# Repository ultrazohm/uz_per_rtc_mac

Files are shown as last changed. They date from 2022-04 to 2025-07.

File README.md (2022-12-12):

# APU Feature Extension Card for the UltraZohm's CarrierBoard/BaseSystem #

This PCB will add some crucial hardware peripherals to the existing systems by means of an extension board to be mounted within the chassis (but not using any of the A/D slots).

### Feature List/Requests/Issues ###

* Low-level configuration storage: Cf. [Issue #124 in the UltraZohm CarrierBoard repo](https://bitbucket.org/ultrazohm/ultrazohm_carrierboard/issues/124/low-level-configuration-storage-ethernet)
* Probably additional user interfaces (buttons/LEDs)
* High-speed storage for OS, application and logs: Cf. [Issue #2 in this repository](https://bitbucket.org/ultrazohm/uz_per_rtc_mac/issues/2/ssd-integration-options)

### How do I get set up? / Contribution guidelines / Who do I talk to? ###

* Eyke and Martin
* Feel free to open an issue here

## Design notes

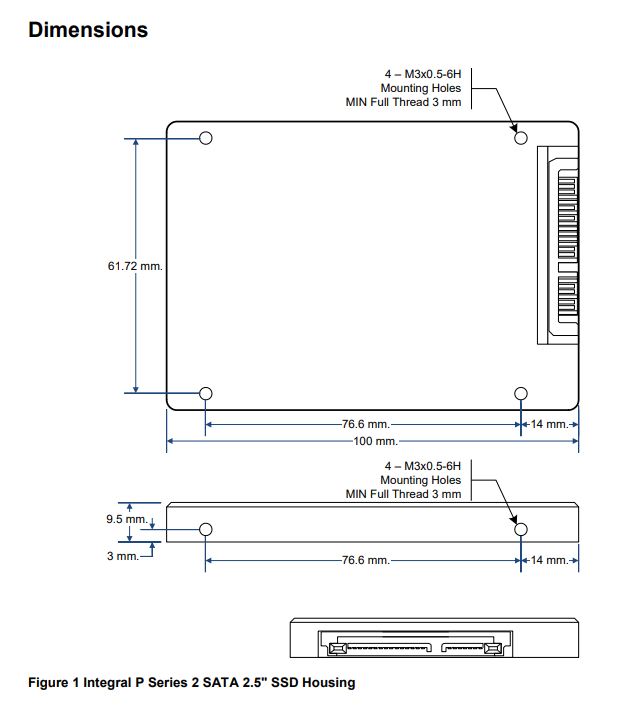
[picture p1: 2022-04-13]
ssd_dimensions.png

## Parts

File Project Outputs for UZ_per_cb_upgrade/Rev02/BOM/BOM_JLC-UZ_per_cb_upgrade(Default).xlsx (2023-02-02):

Quantity | Comment | Designator | MF | MPN | Value | Description | Footprint | Package | Voltage | Dielectric | LCSC Part # | JLCSMT Rotation
1 | HMB1206-03 | B1 |  |  | HMB1206-03 | AUDIO PIEZO BUZZER THT | THT12X6 |  |  |  | C96101
1 | HMB1206-05 | B2 |  |  | HMB1206-05 | AUDIO PIEZO BUZZER THT | THT12X6 |  |  |  | C96095
1 | S8421-45R | BT1 |  |  |  | BATTERY HOLDER COIN 20MM SMD | FP-S8421-45R-MFG |  |  |  | C964790
17 | 100nF | C1, C2, C7, C8, C9, C10A, C10B, C11, C13, C14, C18, C26, C29, C32, C35, C37, C38 |  |  | 100nF | CAP 0603 (1608 Metric) SMD | C_0603(1608)100_L | 0603 |  |  | C14663
12 | 10µF | C3, C4, C12, C20, C21, C22, C23, C24, C27, C30, C33, C36 | Taiyo Yuden | GMK316BJ106KL-T | 10µF | Capacitor 1206 | C_1206 | 1206 | 35 V | X5R | C13585
2 | 10pF | C5, C6 |  |  | 10pF | CAP 0603 (1608 Metric) SMD | C_0603(1608)100_L | 0603 |  |  | C1634
2 | 16pF | C15, C16 |  |  | 16pF | CAP 0603 (1608 Metric) SMD | C_0603(1608)100_L | 0603 |  |  | C1646
2 | 220uF | C17, C19 |  |  | 220uF | ALUMINUM ELECTROLYTIC CAPACITOR | CAPAE9083X105M | 8x10 | 35V |  | C311611
4 | 10nF | C25, C28, C31, C34 |  |  | 10nF | CAP 0603 (1608 Metric) SMD | C_0603(1608)100_L | 0603 |  |  | C100042
1 | 150060RS75000 | D1 | Wuerth Elektronik | 150060RS75000 | 150060RS75000 | WL-SMCW SMD Mono-color Chip LED Waterclear, size 0603, Red, 2 V, 140° | WL-SMCW_0603 | 0603 |  |  | C2286
1 | BAT54C | D2 |  |  |  | Schottky Barrier Diode, 30 V, 2 uA, -55 to 150 degC, 3-Pin SOT23, RoHS, Tape and Reel | NXP-SOT23-3_V |  |  |  | C37704
1 | 1N4148W-7-F | D4 |  |  |  | Fast Switching Diode, 100 V, 0.15 A, -65 to 150 degC, 2-Pin?SOD123, RoHS, Tape and Reel | DIOD-SOD123-2_V |  |  |  | C81598
8 | 150060GS75000 | D5, D6, D7, D8, D9, D10, D11, D12 | Wuerth Elektronik | 150060GS75000 | 150060GS75000 | WL-SMCW SMD Mono-color Chip LED Waterclear, size 0603, Green, 3.2 V, 140° | WL-SMCW_0603 | 0603 |  |  | C72043
2 | HYCW02-SATA07-250B | J1, J2 |  |  |  | CONN HEADER 7POS HOR | HYCW02-SATA07-250B |  |  |  | C2926811
2 | M.2 NGFF Key B Platform Side | J3, J4 |  |  |  | M.2 NGFF Connector Key B Platform Side | 2199230-3 |  |  |  | C590854
2 | M.2 NGFF Socket 2242BM | J3a, J4a |  |  |  | M.2 NGFF Socket 2242BM Snap | M.2-NGFF-Socket-2242BM |  |  |  | C5301784
1 | M.2 NGFF Socket 2280BM | J3b |  |  |  | M.2 NGFF Socket 2280BM Snap | M.2-NGFF-Socket-2280BM |  |  |  | C5301784
2 | 2k | R1, R2 | Yageo | RC0603FR-072KL | 2k | SMD Resistor 0603 | R_0603_N | 0603 | 75 V |  | C22975
9 | 680R | R3, R18, R22, R23, R28, R31, R32, R33, R34 | Bourns | CR0603-FX-3901ELF | 680R | SMD Resistor 0603 | R_0603_N | 0603 | 75V |  | C23228
39 | 0R | R5, R6, R7, R10, R11, R12, R13, R14, R15, R25, R26, R27, R29, R30, R36, R38, R52B, R54A, R54B, R55A, R55B, R56A, R56B, R57A, R58A, R58B, R59, R60, R63, R64, R65, R66, R67, R68, R69, R70, R72, R73, R86 |  |  | 0R | SMD Resistor 0603 | R_0603_N | 0603 | 75V |  | C21189
10 | 10k | R35, R37, R39, R40, R41, R47, R49, R62, R76, R77 | Yageo | RC0603FR-072KL | 10k | SMD Resistor 0603 | R_0603_N | 0603 | 75 V |  | C25804
1 | 100k | R42 |  |  | 100k | SMD Resistor 0603 | R_0603_N | 0603 |  |  | C25803
4 | 33 | R78, R80, R82, R84 |  |  | 33 | SMD Resistor 0603 | R_0603_N | 0603 |  |  | C108661
4 | 49.9 | R79, R81, R83, R85 |  |  | 49.9 | SMD Resistor 0603 | R_0603_N | 0603 |  |  | C114625
1 | 475 | R87 |  |  | 475 | SMD Resistor 0603 | R_0603_N | 0603 |  |  | C137716
3 | EVQ-Q2F03W | SW1, SW2, SW3 |  |  |  | SWITCH TACTILE SPST-NO 0.02A 15V | FP-EVQ-Q2F03W-MFG |  |  |  | C318884
1 | PCF8563T/5,518 | U1 |  |  |  | IC RTC CLK/CALENDAR I2C 8-SOIC | FP-SOT96-1-IPC_B | SOT96-1 |  |  | C7440
1 | AT24C02C-SSHM-T | U2 |  |  |  | IC EEPROM 2K I2C 1MHZ 8SOIC | FP-C04-057-SN-MFG | C04-057-SN |  |  | C6203
1 | PCA9535PWR | U3 |  |  |  | IC I/O EXPANDER I2C 16B 24TSSOP | FP-PW0024A-MFG |  |  |  | C255606
2 | 24AA025E48T-I/SN | U4A, U4B |  |  |  | 2K bits I2C™ Serial EEPROM with EUI-48™ Node Identity, 1.7 to 5.5 V, 400 kHz, -40 to 85 degC, 8-pin SOIC (SN8), Tape and Reel | MCHP-SOIC-SN8_L |  |  |  | C2060925
1 | AOZ1360AIL | U5 |  |  |  | 28V Programmable Current-Limited Load Switch | SOIC127P600X175-8N |  |  |  | C146821
1 | ULN2803ADWR | U6 |  |  |  | Darlington Transistor Array, -40 to 85 degC, 18-Pin SOIC (DW), Green (RoHS & no Sb/Br), Tape and Reel | DW0018A_L |  |  |  | C181731
1 | TDKxx-yySzz | U8 |  |  |  | Isolated Single Output DC/DC Converter, 15/20/30 W, 2x6-Pin DIP (*M*iddle and *S*ide pin-out in one footprint/package, hopefully) | TDKxx-yySzz |  |  |  | C570789
1 | AZ1084CD-3.3TRG1 | U9 |  |  |  | 5A Low Dropout Positive Regulators, 3-pin TO-252-2(DPAK) | DPAK457P1010X238-3N |  |  |  | C151391
1 | PI6C557-03ALEX | U10 |  |  |  | Clock Generators & Support Products PCI express Gen 2 2 ouput clock gen | SOP65P640X120-16N |  |  |  | C500785
1 | IPL1-106-01-L-D-K | X1 | SAMTEC | IPL1-106-01-L-D-K | IPL1-106-01-L-D-K | 2.54mm Double Row Terminal Assembly, Right-Angled | IPL1-106-01-L-D-K |  |  |  | C5295959
2 | IPL1-113-02-L-D-K | X5, X6 |  |  |  | IPL1-113-02-L-D-K | IPL1-113-02-L-D-K |  |  |  | C5290052
1 | ABS07-32.768KHz-T | Y1 |  |  |  | CRYSTAL 32.7680KHZ 12.5PF SMD | FP-ABS07-MFG |  |  |  | C32346
1 | Q22FA12800120 | Y2 |  |  |  | SMD Crystal Resonators 24MHz +/-10ppm SMD-2016_4P RoHS | Q22FA12800120

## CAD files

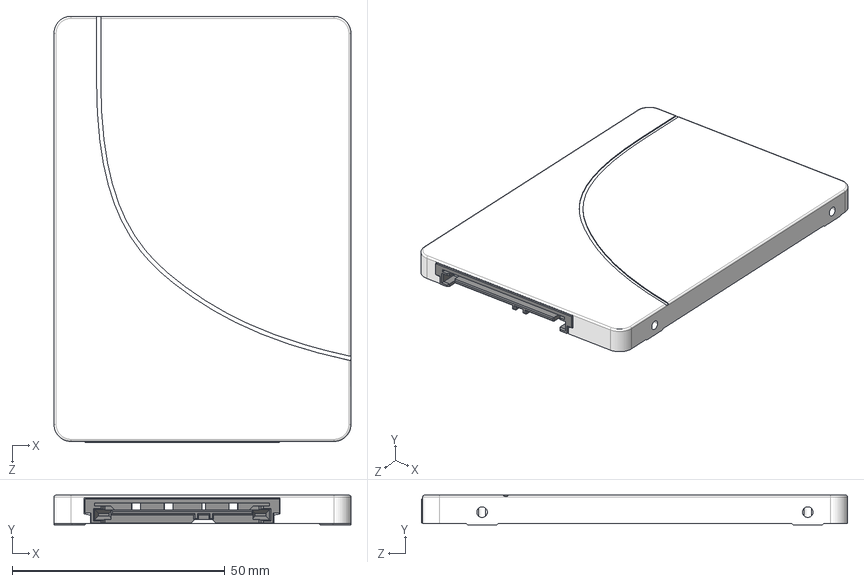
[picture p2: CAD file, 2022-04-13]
3D/Standard 520 model.STEP
69.8 x 7.00 x 100.3 mm

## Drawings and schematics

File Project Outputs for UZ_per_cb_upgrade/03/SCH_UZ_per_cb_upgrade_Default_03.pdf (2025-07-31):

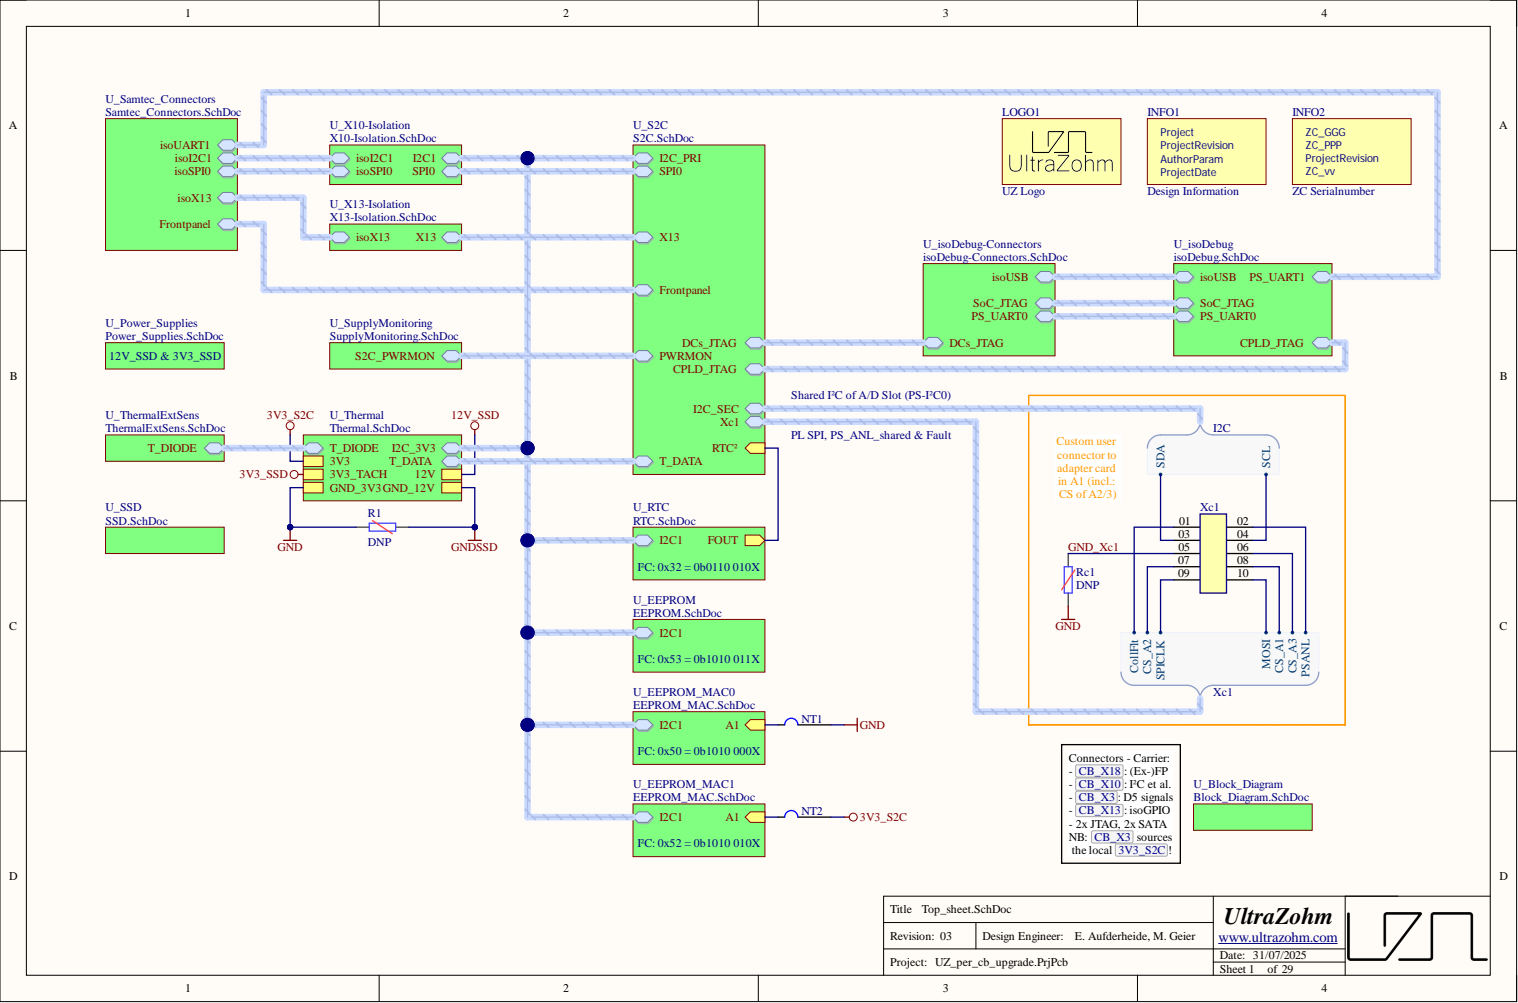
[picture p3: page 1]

Shared I²C of A/D Slot (PS-I²C0)

05 | | 06
07 | | 08
09 | | 10

Revision:

Date:

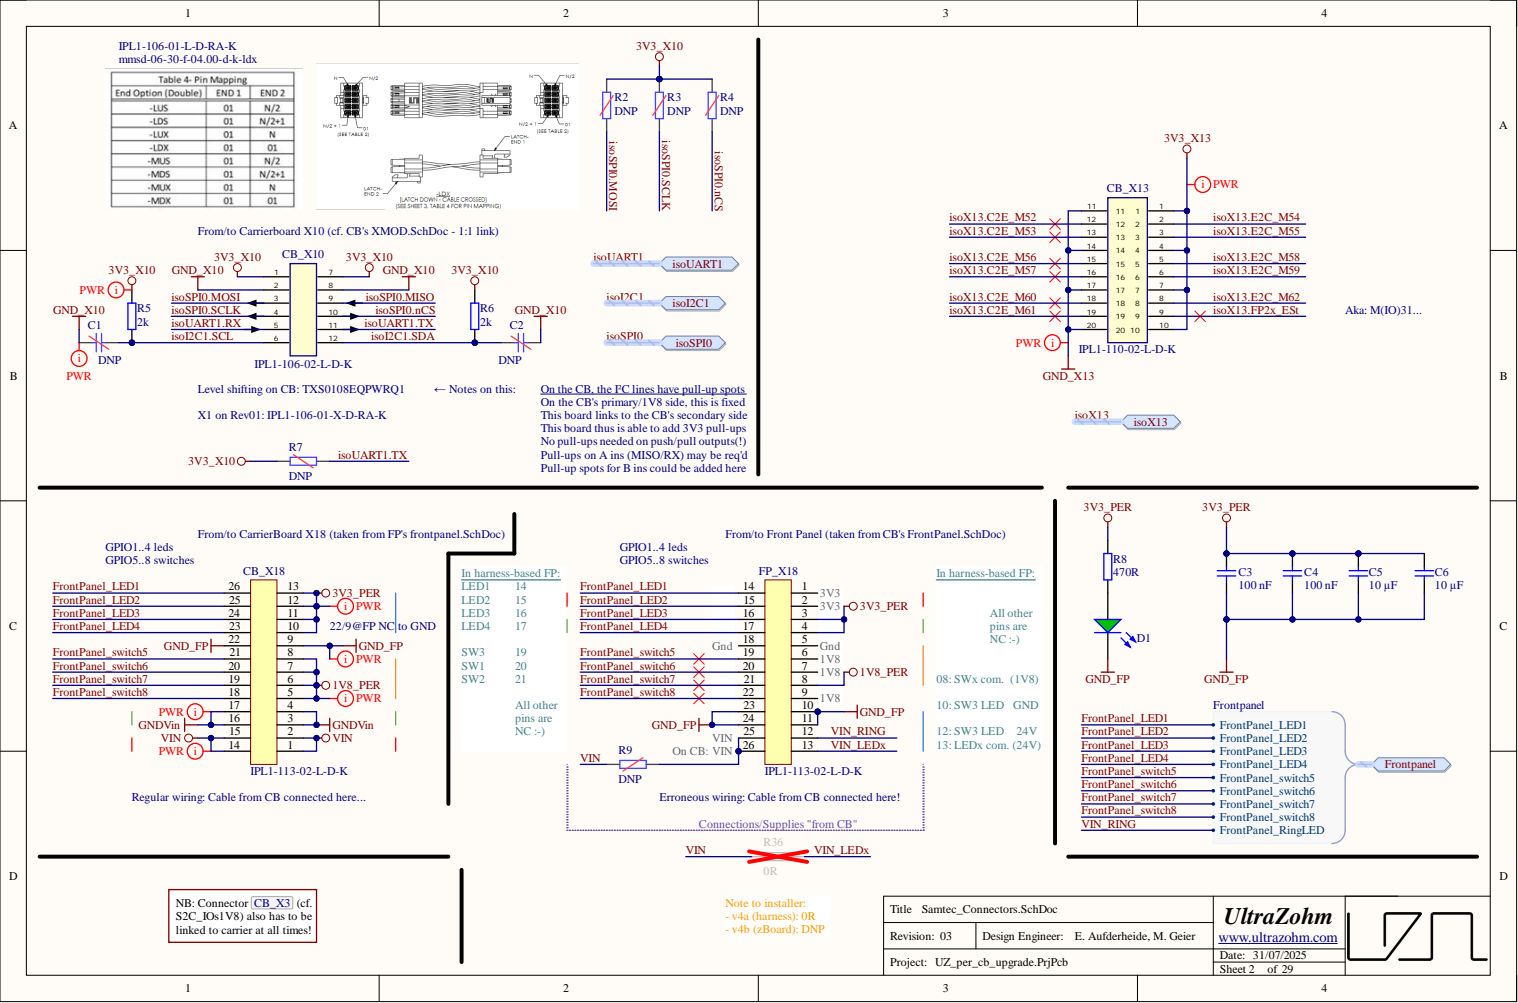
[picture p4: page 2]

From/to Carrierboard X10 (cf. CB's XMOD.SchDoc - 1:1 link)

Level shifting on CB: TXS0108EQPWRQ1

On the CB's primary/1V8 side, this is fixed
This board links to the CB's secondary side
This board thus is able to add 3V3 pull-ups
No pull-ups needed on push/pull outputs(!)
Pull-ups on A ins (MISO/RX) may be req'd
Pull-up spots for B ins could be added here

From/to CarrierBoard X18 (taken from FP's frontpanel.SchDoc)

From/to Front Panel (taken from CB's FrontPanel.SchDoc)

In harness-based FP:

NB: Connector CB_X3 (cf.
S2C_IOs1V8) also has to be
linked to carrier at all times!

Rev i s n : | Des gn E gi neer: E. A u fderhei de, M. Geier

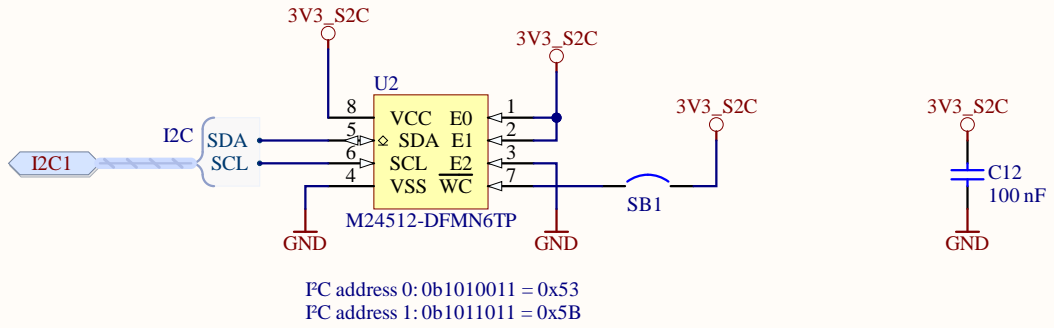
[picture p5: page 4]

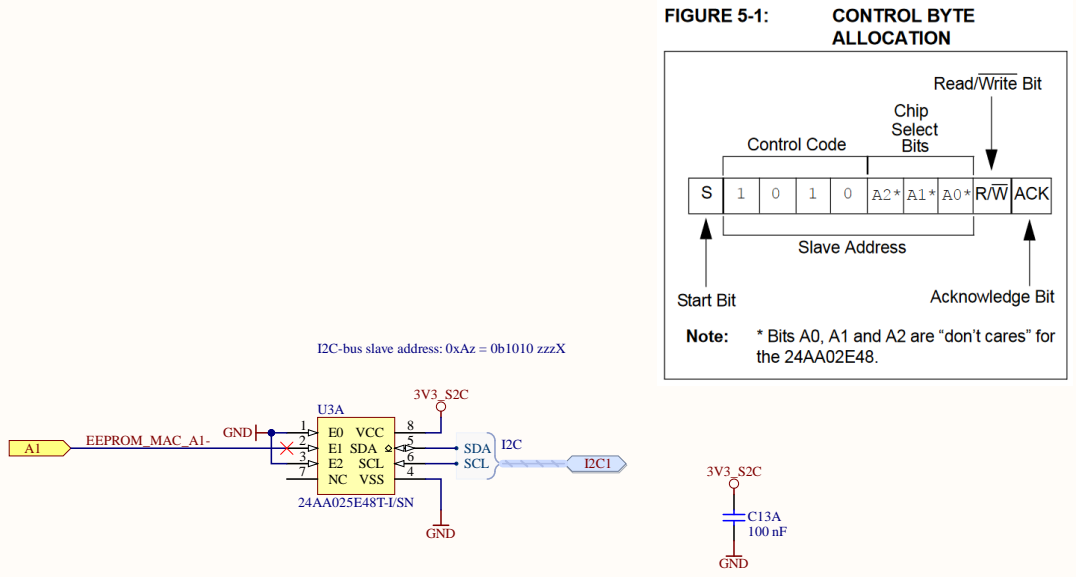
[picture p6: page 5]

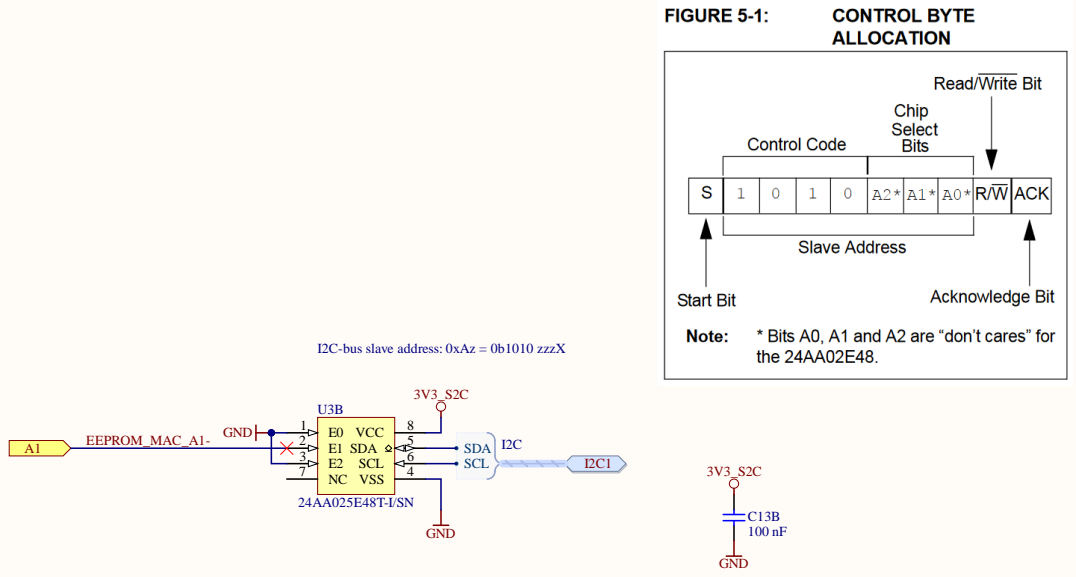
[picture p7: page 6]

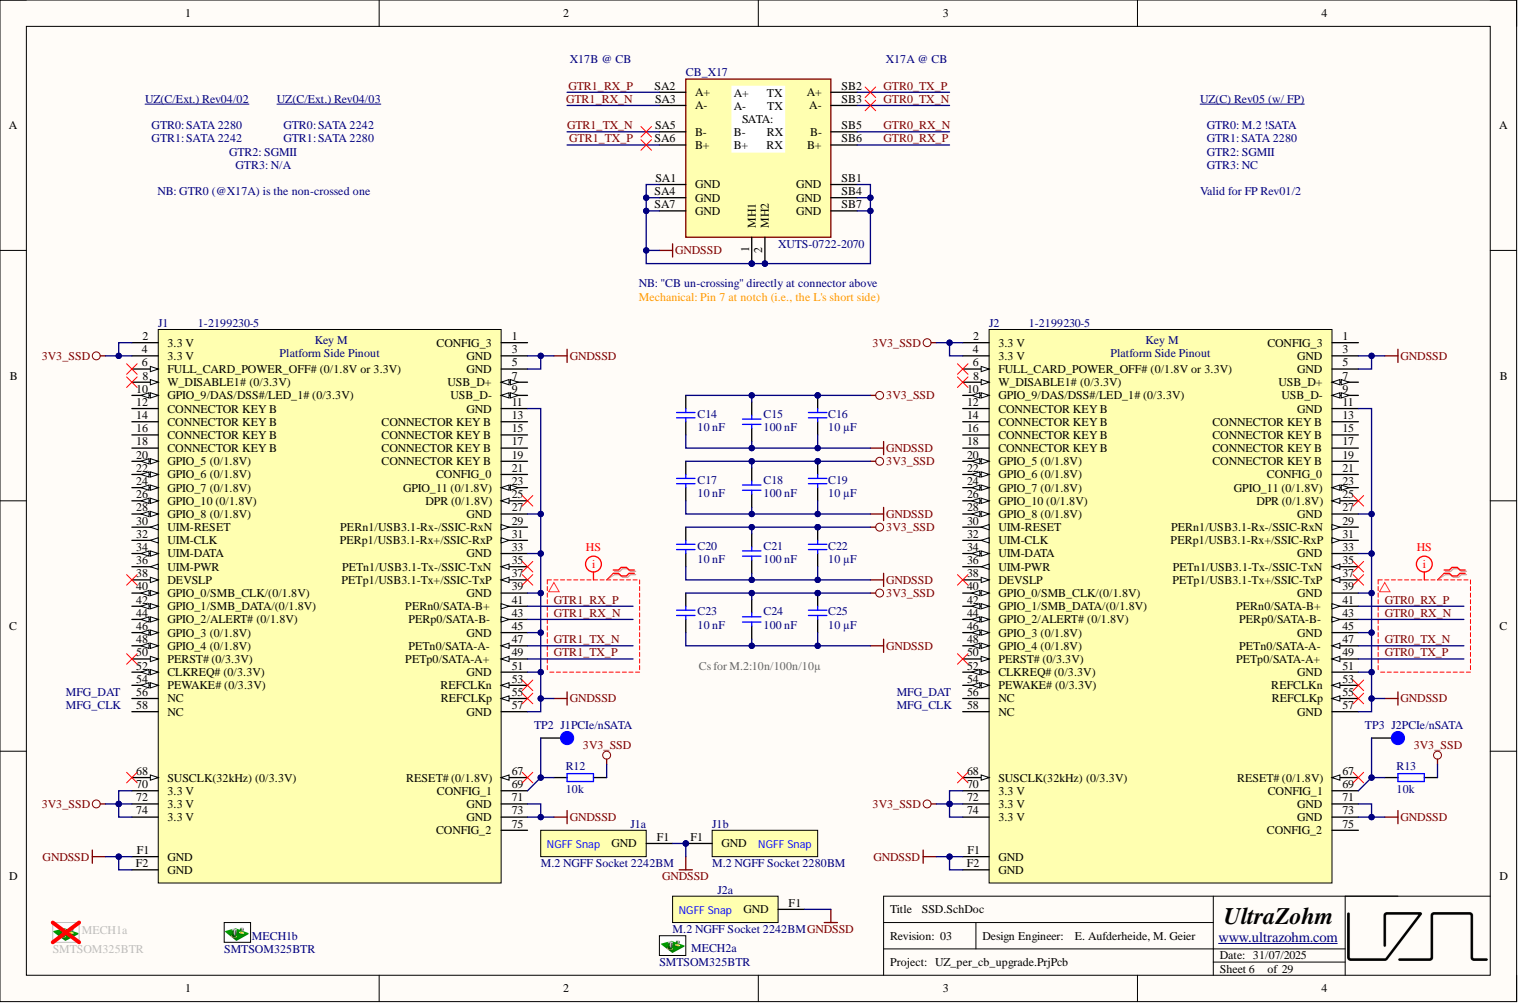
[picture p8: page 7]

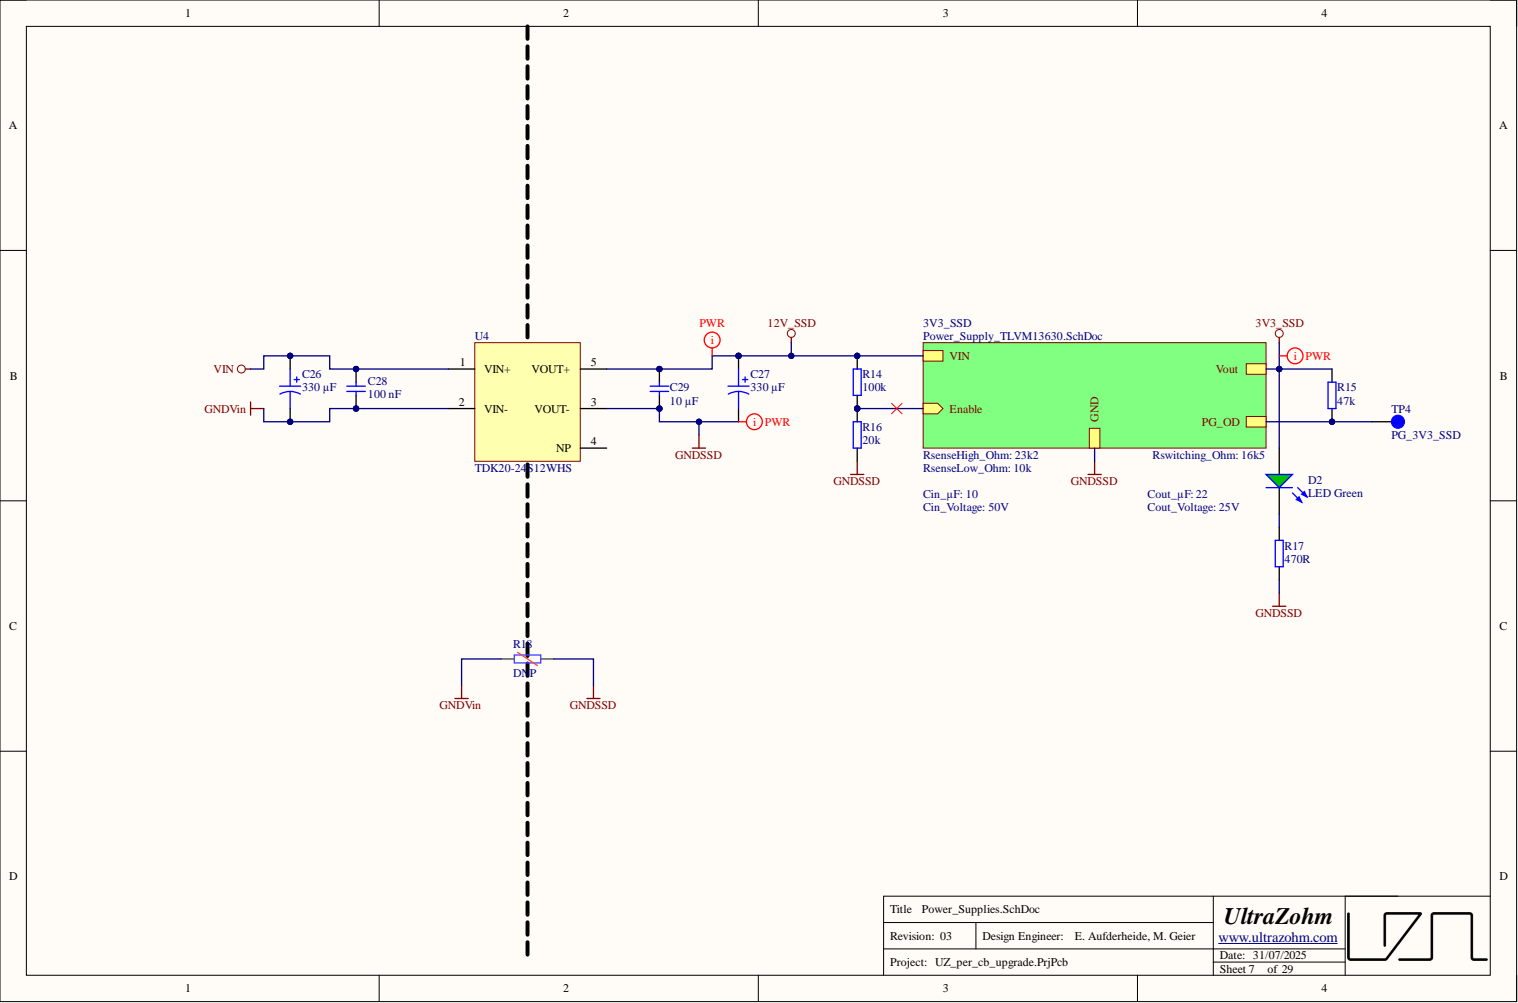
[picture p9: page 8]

E nab l e

2 8

1 8
1 9

1 7 | 9
2 9 | 1 0

VCCv 2 3 | 1 2

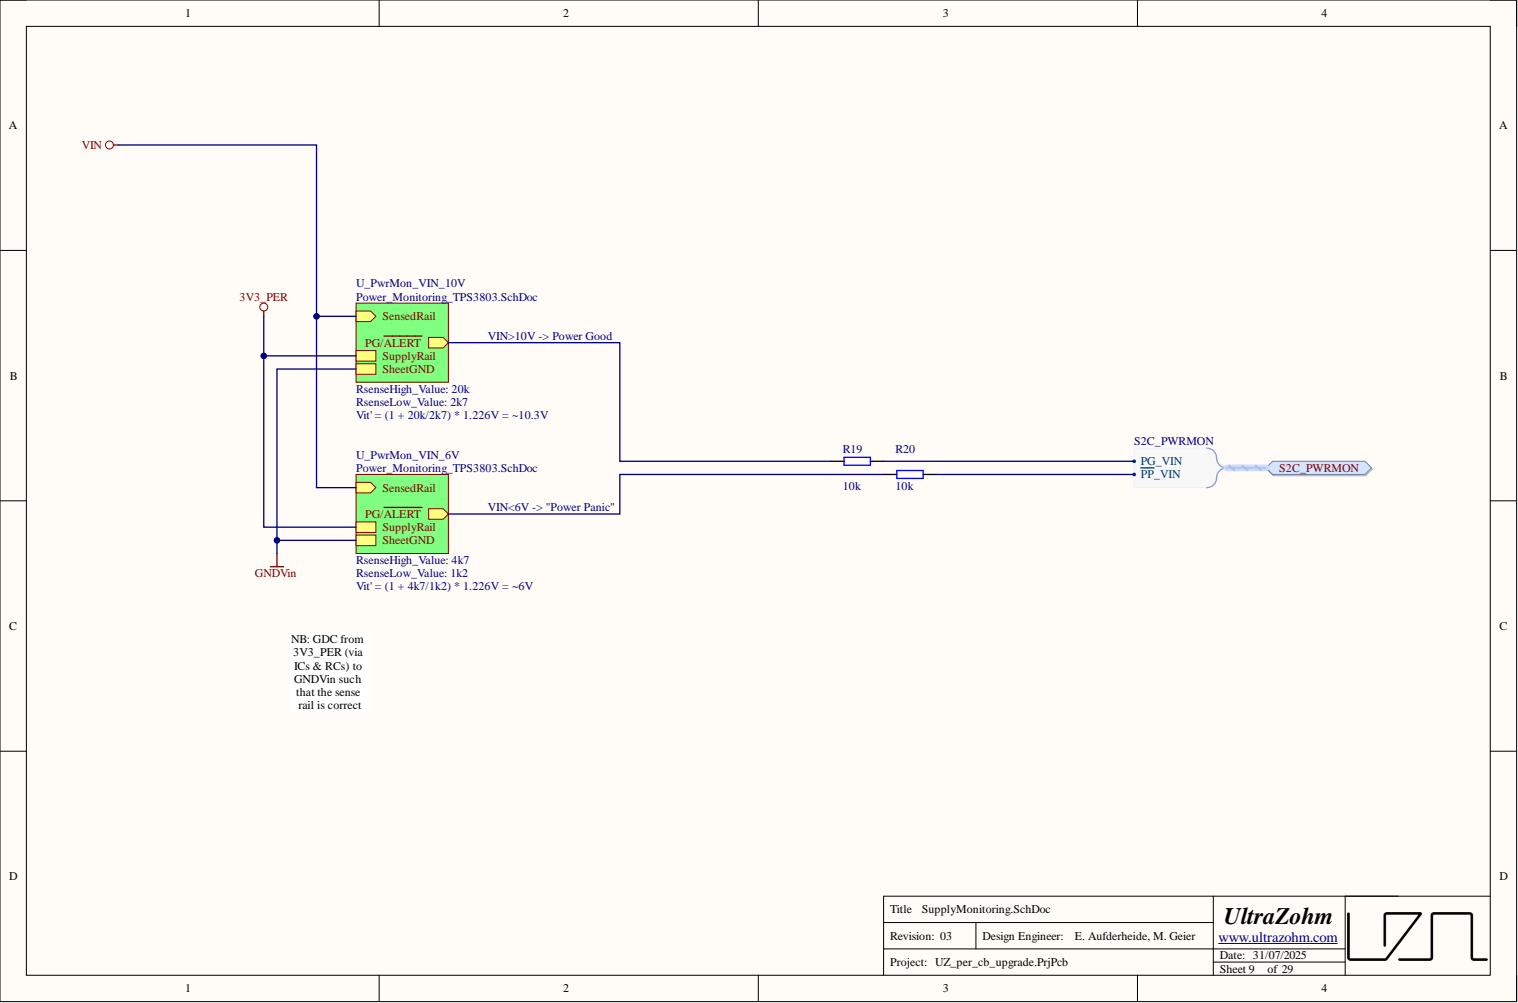
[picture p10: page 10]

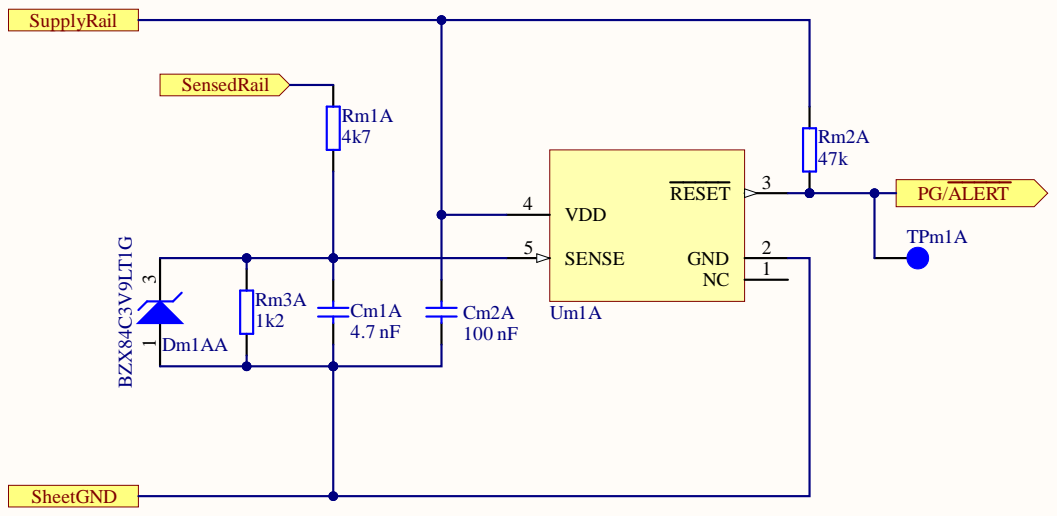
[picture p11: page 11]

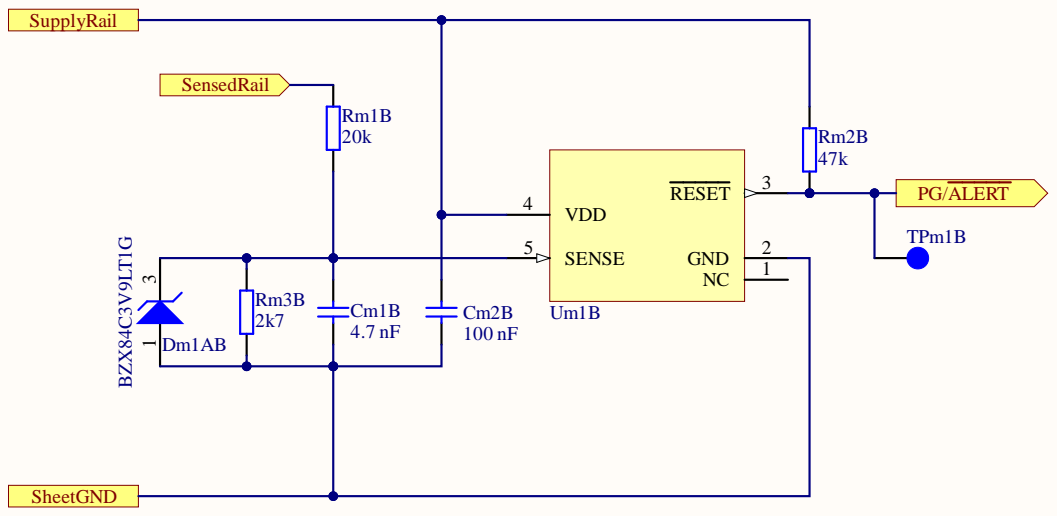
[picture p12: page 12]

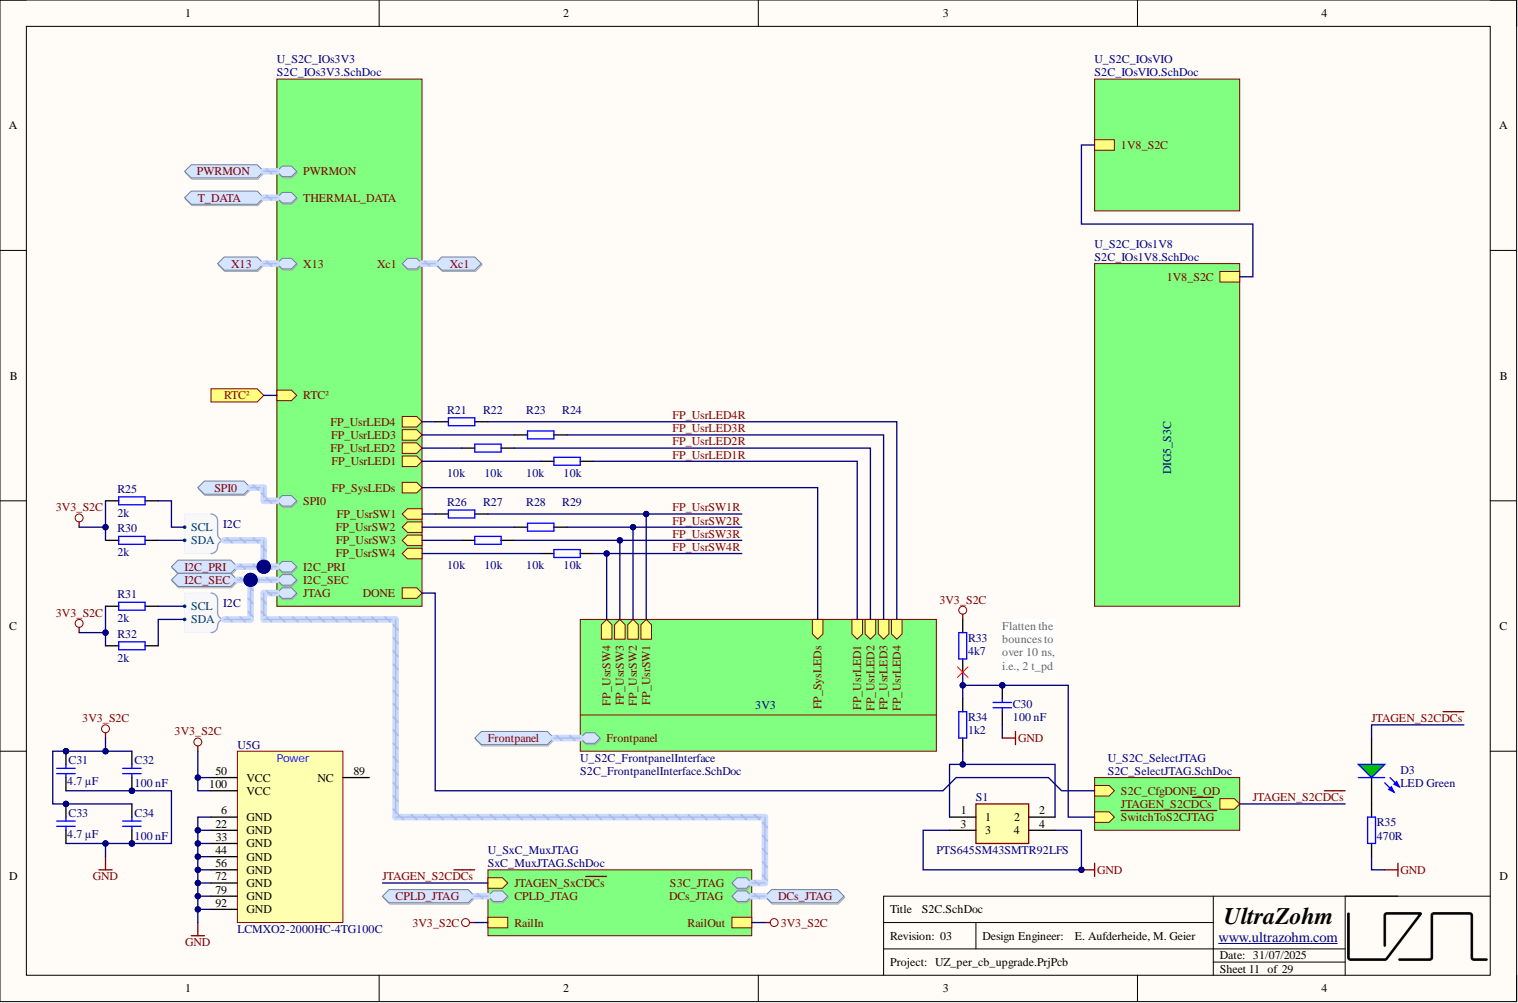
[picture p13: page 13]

FP_ U srL E D 2 R

R2 6 R2 | 7 | R2 8 R2 | 9 | FP_ U srSW 1 R

PT16D/TMS 90

THERMAL_DATA.SHDN | PB21A 42

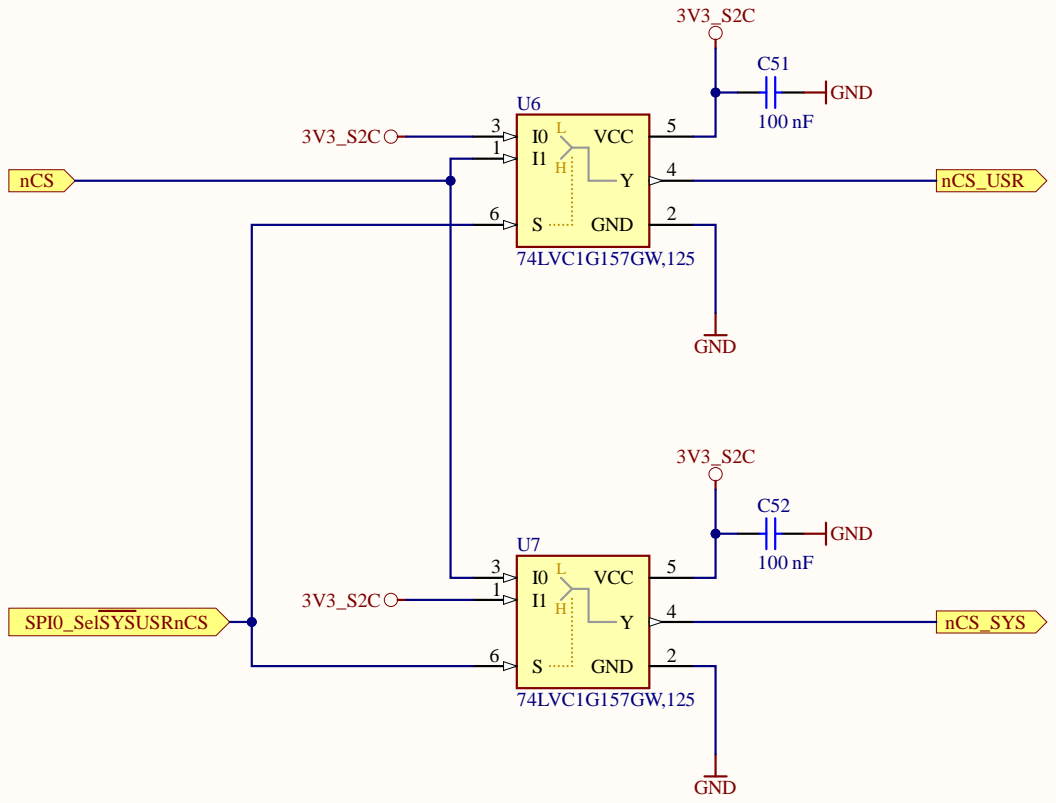
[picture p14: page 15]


4 4
5 5
6 6
7 7
8 8
9 9



SwitchToS2CJTAG ...
- is only read if(f) S2C_CfgDONE_OD has
high level, i.e., after a rising edge (may it
be during ramp-up or due to S²C refresh);
- forces the JTAG mux into "switch to S²C"
if asserted (i.e., driven low);
- has two sources
- a dual-use (reset and debounce) RC logic
based on R33 and C30 , and
- a "switch to S²C" button (S1 );
- has, at ramp-up, to be high before the S²C-
based rising edge on S2C_CfgDONE_OD
for the switch-over (to the five D CPLDs)
to be successful; and
- thus needs an RC time constant in the sub-
ms range (as config time is going to vary).

OE 7 DIR1 | 15

DIR2 | 16

DIR3 GND 8 | 5

NB: JTAGEN_SxCD\C\s\
has a signal level of RailIn


5B 5 | FP.FrontPanel_LED1 FP.FrontPanel_LED2 FP.FrontPanel_LED3 FP.FrontPanel_LED4

GND (buttons) vs. GND_FP (LEDs)

NB: SS most likely should not be
wired to IN due to its AMR (6V)!

SS: capacitive range is 0.001 μF to 0.1 μF







TACH 1 TACH 2 PW M N.C.

1 2 | 9 | FA N_ TACH 2
1 1 | 6 | FA N_PW M

Ct 1
2.2 n F



I²C, SSD and S²C Extension for Rev04-UZC-based UltraZohm systems

Partial retrofit of features that are available as standard in Rev05-UZC-based systems such as Linux/network support (EEPROMs), storage (SATA SSD), isolated USB-JTAG/UART, thermal management and a Hw-programmable Controller (S²C) for monitoring, I/O, ...

I/O planning for "onboard S²C":
- B0 (3V3): JTAG, I²C1, DONE
- B1 (3V3): RTC, 7+2x A1, tbd
- B2 (3V3): 6x SPI0, 9x FP, M.
- B3 (1V8): 6x X3 | 11+1 MIOs
- B4 (1V8): 6x X3 | are on B0/1
- B5 (flex): 8x I/O at user supply
Max. bank I/Os: 19/21/20/6/6/8

NB: SSD(s) and fan(s)
jointly limited to 20W

11 PS MIOs (with predefined directions) and External STOP

NB: CS multiplexing (between user and system SPI)
Multiplexing controlled by S²C pin (default: system)

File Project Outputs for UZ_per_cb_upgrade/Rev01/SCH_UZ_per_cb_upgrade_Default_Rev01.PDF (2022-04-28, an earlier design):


Rev i s n

Dat e :


with optional 10k to GND, identical to Carrierboard config

Revision:

Date: 27.04.2022


evtl auf gpio legen?

Check value of Cap 12.5pF

Revision:

Date: 27.04.2022


A 0 _ E EPR O M
A 1 _ E EPR O M | 2
A 2 _ E EPR O M | 3


I2C_ S D A | R3 0
I2C_SCL | 0 R


A 1 | 2
A 2 | 3


A 1 | 2
A 2 | 3

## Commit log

2022-04-10 initial commit of altium project
    [EEPROM.SchDoc, GPIO_Expander.SchDoc, RTC.SchDoc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]
2022-04-10 update routing
    [UZ_per_cb_upgrade.PcbDoc, UZ_per_cb_upgrade.PrjPcb]
2022-04-13 store status
    [EEPROM.SchDoc, EEPROM_MAC.SchDoc, GPIO_Expander.SchDoc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]
2022-04-19 save status
    [GPIO_Expander.SchDoc, RTC.SchDoc, Top_sheet.SchDoc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]
2022-04-20 ordered version Rev01
    [EEPROM.SchDoc, EEPROM_MAC.SchDoc, GPIO_Expander.SchDoc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]
2022-12-12 add libraries from initial design
    [UZ_per_cb_upgrade.PcbLib, UZ_per_cb_upgrade.SCHLIB]
2022-12-15 Step one (of many?) towards Rev02
    [GPIO_Expander.SchDoc, SSD.SchDoc, Top_sheet.SchDoc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]
2022-12-15 add ipl1-13-d-l-02
    [XMOD.SchDoc]
2022-12-19 Step two (of many?) towards Rev02, prepare to replace IPL1-106-02-L-D-K and add M.2
    [GPIO_Expander.SchDoc, SSD.SchDoc, UZ_per_cb_upgrade.PrjPcb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]
2022-12-19 - add ipl106-01-d - add m.2 connector - add m.2 card snap
    [SSD.SchDoc, XMOD.SchDoc]
2022-12-19 add TO-252-3 pcb footprint ( AZ1084CD-3.3TRG1 )
2022-12-20 Step three (of many?) towards Ref02, prepare for third M.2 snap
    [SSD.SchDoc]
2022-12-20 add footprint and symbol oszillator Q22FA12800
2022-12-20 Step four (of many?) towards Rev02, prepare for BoM
    [EEPROM_MAC.SchDoc, GPIO_Expander.SchDoc, SSD.SchDoc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]
2022-12-20 Add missing LCSC Part # of X1/X2
    [XMOD.SchDoc]
2022-12-20 Add missing LCSC Part # of R42
    [GPIO_Expander.SchDoc]
2022-12-20 Change Type of J3a/b and J4a to Standard
    [SSD.SchDoc]
2022-12-20 Step five (of many?) towards Rev02, prepare for M.2 clocks and data
    [SSD.SchDoc]
2022-12-21 Step six (of many?) towards Rev02
    [SSD.SchDoc, XMOD.SchDoc]
2022-12-21 Step seven (of many?) towards Rev02, prepare for layer stackup
    [UZ_per_cb_upgrade.PrjPcb]
2022-12-21 Step eight (of many?) towards Rev02, finalize M.2 while waiting for layer stackup
    [SSD.SchDoc, UZ_per_cb_upgrade.PrjPcb, XMOD.SchDoc]
2022-12-21 Fix 50 Ohm diff pairs
    [SSD.SchDoc]
2022-12-21 - add rules for "50" ohm differential - add net differential parameter D50
    [SSD.SchDoc]
2022-12-21 Fix INA (set DNP)
    [SSD.SchDoc, UZ_per_cb_upgrade.PrjPcb]
2022-12-21 Unify naming of address signals
    [EEPROM_MAC.SchDoc]
2022-12-21 Minor schematic tweaks and finalize DNPs
    [GPIO_Expander.SchDoc, SSD.SchDoc, UZ_per_cb_upgrade.PrjPcb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]
2022-12-22 Swap LEDs and Rs
    [GPIO_Expander.SchDoc]
2022-12-23 Routing done, pending review...
    [GPIO_Expander.SchDoc, UZ_per_cb_upgrade.PrjPcb]
2022-12-23 fix footprint of dcdc
2022-12-26 Fix DC/DC and minor tweaks
    [UZ_per_cb_upgrade.PrjPcb]
2022-12-27 change footprint of buzzer to leave layer m1 empty
2022-12-29 add abstandsbolzen als bauteil mit eigenem orgin für pick and place
    [SSD.SchDoc, UZ_per_cb_upgrade.PrjPcb]
2022-12-29 kurze M.2 Steckvariante Lötmutter -> DNP
    [SSD.SchDoc, UZ_per_cb_upgrade.PrjPcb]
2023-01-19 tiny clean up, flipping symbols and making wires more straight
    [SSD.SchDoc]
2023-02-02 production files Rev01 und Rev02
    [BOM_JLC-UZ_per_cb_upgrade(Default).xlsx, Pick Place for UZ_per_cb_upgrade(Default).csv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]
2025-05-30 clean up libraries, update (board and schematic) to Rev03, and add part map for UZgen workflow (as used in production)
    [BOM_JLC-UZ_per_cb_upgrade(Default)-UZgenPartsMap.csv, Block_Diagram.SchDoc, EEPROM.SchDoc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]
2025-06-15 rename sheets
    [S2C.SchDoc, Samtec_Connectors.SchDoc, Top_sheet.SchDoc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]
2025-06-15 (re)set and inherit metadata, respectively (for schematic)
    [Block_Diagram.SchDoc, EEPROM.SchDoc, EEPROM_MAC.SchDoc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]
2025-07-30 optimize schematic
    [Power_Supplies.SchDoc]
2025-07-31 final schematic (PDF)
